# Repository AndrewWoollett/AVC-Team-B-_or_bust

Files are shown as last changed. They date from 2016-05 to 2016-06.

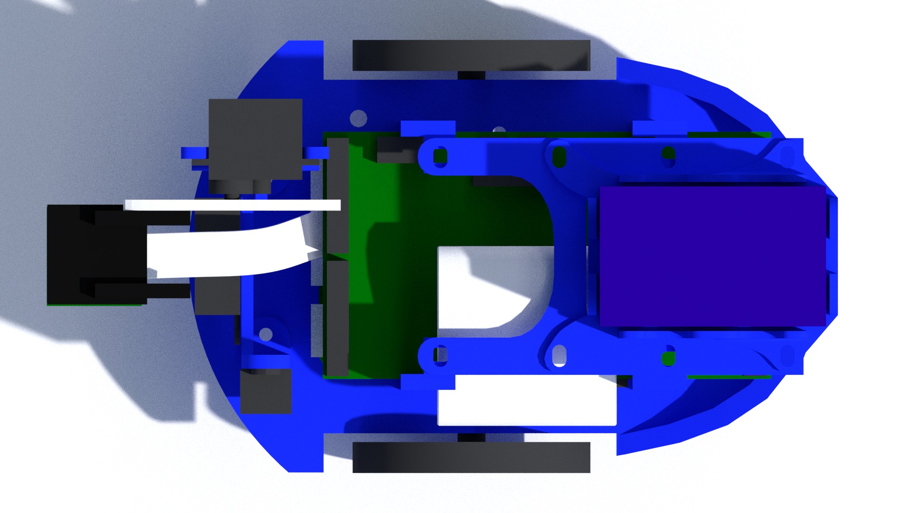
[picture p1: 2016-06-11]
Design/Images/Top.jpg

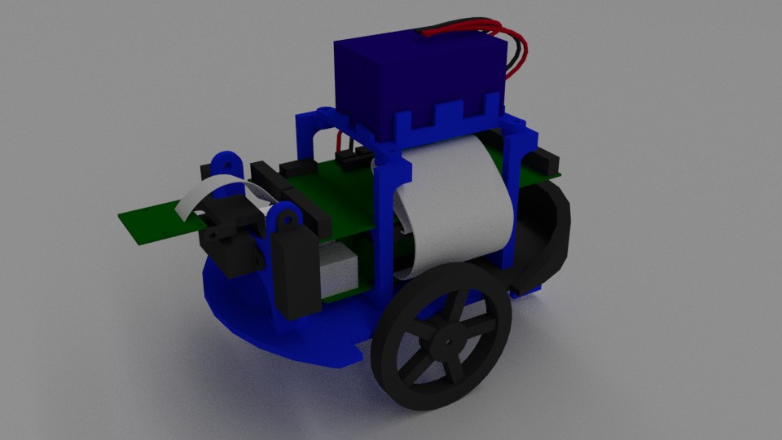
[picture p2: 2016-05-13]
Design/Images/0000.jpg

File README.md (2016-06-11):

# AVC-Team-B-_or_bust
Team repository for the AVC Project in ENGR101.
Team members include: David Scott, Daniel Sommerville, Ana Ramirez, Daniel Van Eijck and Andrew Woollett

Week 1 Plan (22nd April, just before the holidays/during the holidays)
Andrew: Set up the Github repository
David: Go over the AVC plan to make sure everything is completed
Daniel: SSH into the RPi
Daniel S: Put together the initial hardware components
Ana: Create weekly plan (table) and get key dates and people organised

Week 1 Review:
(Since it was the holidays, we only set up very simple goals as we knew we would not be able to complete much while away from uni).
Everyone completed their respective tasks for this week and we got the AVC plan in on time before the holidays.

Week 2 Plan (28th April, During and after the holidays):
(Minor work as part of this week is during the holidays and wouldnt be able to organise team meetings)
Andrew: Review and go over the skeleton code
David: Planning of the code to get the sensor working
Daniel V: Planning the code to get the robot working
Daniel S: Startng designing hardware construction
Ana: Arrange communication, sorting out meetings outside of lab time.

Week 2 Review:
Because of the holidays, again we couldn't get a lot done in terms of coding, but we did as a group go over the skeleton code and began planning how to go about building on the skeleton code to get the basic function of the robot working.
Daniel made a full detailed plan of the design and hardware of the robot that he created on Blender. He had also already 3D printed a few of the basic components of the hardware.
Daniel V, Andrew, and Ana had a few problems with SSH-ing into the Rpi and finding the IP address, but this was just through simple errors of our own, rather than technical issues with the RPi.

Week 3 Plan (5th May):
Andrew: Begin coding to get the sensors working so that the basic "detection" part of the robot is operational
David: Continue producing documentation and overseeing and providing help with software
Daniel V: With Andrew, begin coding to get the sensors working so that the basic "detection" part of the robot is operational and begin on the basic movement of the robot
Daniel S: Continue with the construction, design, and printing of the hardware to have it completed by the start of our next official lab time (12th May).
Ana: Arrange meetings and delegate tasks as well as assist with the documentation and software

Week 3 Review:
We had a few issues this week with our RPi. On Friday, our robot short circuited, we believe because Daniel was constructing the robot while it was still turned on, resulting in a lot of our planned meeting time being used by trying to fix it. In the end, we had a to ask Elf for help, who gave us a new SD card.
This meant that we lost a lot of the code that we'd been working on since we were working on the Pi itself and hadn't uploaded any of the code to GitHub. Because of this, we've had to work significantly harder this week in order to regain our lost time and files.
Aside from our issues, Daniel S successfully completed printing out all the hardware and construction of the robot so that it is practical and functional, yet follows the "aesthetic" requirements of the project.
Andrew and Daniel S have both been working on regaining and improving the code that we have lost, with assistance from David and Ana. At the end of this week we have committed and saved and committed several files to GitHub for the software, but haven't actually run or tested anything yet, which we plan to do in our next meeting (12th May).

Week 4 Plan (12th May):
As an overall goal as a group, by our next designated lab time, we aim to be testing our robot on the official board, and hopefully be running the robot up to the B- mark (end of the second quadrant).
Andrew: Develop the code to enable the robot to turn at dead ends
David: Continue with documentation and assist with developing the code to get the robot to turn around the curved corners
Daniel V: Develop the code to enable the robot to turn at dead ends
Daniel S: Design a new back wheel and figure out a way for the robot to fit turn inside the maze.
Ana: Continue with documentation and assist with developing the code to get the robot to turn around the curved corners, as well as go over the code to get the gate opening (written by Daniel V), test it, and get it functional.

Week 4 Review (so far):
David has not showed up for our Thursday lab or the extra meeting we scheduled on Friday (absence yet to be explained).
Daniel S put the finishing touches on the hardware of robot, so that this part is complete so we are now free to run code on the robot to test it officially. We ran into a few problems when trying to test our code, one of them being that our RPi didn't have the lt and makefile files. So we asked Arthur and he gave us another updated SD card (again) with the correct files on it this time. By the end of Thursday's lab we had the robot moving and operational. It could roughly dectect a line and attempts very roughly to rectify itself back onto the line when it goes astray, however, we are still very pleased with this progress.
After our extra meeting on Friday (attended by Daniel V, Daniel S, and Ana), we made even further progress. We haven't got the gate working yet as we have been concentrating on getting the robot to follow the path, which at the moment it successfully does up until the second curve in the path (it can get through the first curve as it is not as sharp as the second curve).
By the end of the week (on Thursday the 19th), the robot was able to complete up to the B- mark on the path, meaning that one of our main goals was achieved. We also managed to fix the problem of the robot tipping over when it reversed (because of weight distribution), by relocating the placement of the battery on the robot. We noted that the back wheel of our robot was slightly faulty and meant that the robot occasionally went off on the wrong direction, so we made the plan to replace this wheel with a marble so it is able to move more freely. Daniel wrote down a lot of his testing process this week in order to get the camera sensing the line properly in order to get it up to the B- mark, as well as figuring out how to deal with T junctions and dead-ends. This documentation can be found in the document “Daniel’s Documentation (week 4)”

Week 5 plan (19th May): Our overall group goal this week is to get the robot operational up to the entrance to the maze, and have a plan of how to code the maze. 
Daniel V and Daniel S: refine code further so that the robot is able to deal with right angled turns, T junctions, and dead ends, so that the robot can reach the entrance of the maze.
Ana: Continue with the documentation.
David, Andrew, and Ana: begin researching and working on a plan of how to get the robot to complete the maze.

Week 5 Review: this week we kept running into the regular problem of the lab being constantly full, so much so that we weren’t allowed in unless it was our regular lab time, or that only1 or 2 members of the team were allowed in at once. In this situation of only a few team members being allowed in at once, we decided to place getting the robot up to the entrance of the maze as a priority over beginning working on the maze code, which meant that we didn’t advance very quickly with our maze code this week. However, by the end of the week, we successfully got the robot reaching the entrance of the maze with around 80% consistency. PID just needs to be refined further in order to get this working. And we did end up with a general plan on how to tackle the maze code, and managed to get the sensors to detect the red square at the start of the maze, so that the sensors are activated.

Week 6 plan (26th May): We predict that since this is the final week of the AVC until it is tested, the lab will be packed almost all the time, so our only options are to get in early, or to work on code outside the lab. We are currently feeling very confident about our robot, so we have set the goal of the robot completing 100% of the maze by the time it comes to be tested.
Daniel V: refine PID so that the robot is able to follow the tape more consistently.
Rest of the team: create the Maze code and the PID for the sensors.

Week 6 Review: As we predicted, it is very difficult this week to get spots in the lab, so we ended up meeting outside the lab to create some basic maze code that we would test on the robot at our next opportunity. This rough code worked very well as a starter, so from here we began to create the PID for the robot. Daniel V refined the code further so that it could get up to the entrance of the maze much faster and at a more consistently. However, an issue keeps coming up where at the first right angled junction (before the B- mark), the robot goes into the dead end, and to escape it, it reverses, and then retraces its steps, back to the start of the maze. This occurs probably 40% of the time, and we’ve decided that there’s nothing much we can do about it, and it will be ok, especially since during the final testing, we are allowed to restart the robot as many times as we want within those 15 minutes. After implementing the maze PID, we had a few errors were occasionally the robot would get stuck on a corner, but improving PID fixed this issue fairly easily. By Tuesday the 31st (2 days before our final test), the robot was able to fully complete all 4 quadrants fairly consistently and at a decent speed. On Thursday, our robot was officially tested, and completed 100% of the maze, sending us to an A+, in 1 minute 5 seconds, a time and grade that we were all very happy with, and because of this, we made it into The AVC finals, to face off against the rest of the highest scoring robots.

AVC Finals: Our main plan for the AVC finals was just to increase the robot's speed without decreasing its ability to move through the board and maze, so we simply increased the speed slightly, and edited out the gate code (since there was no gate in the finals). When our robot came to be tested, it completed the course in 1 minute 1 second, which ended up being the fastest robot out of all the others, meaning that our group took out the award for the fastest AVC robot.

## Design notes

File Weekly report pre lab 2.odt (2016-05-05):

Pre 2nd lab progress.

Design

Model is designed complete and is just awaiting printing and tests. The only problems we have spotted with it so far is that if the robot may tip forward if stopped suddenly. Though this may be fine as our robot is back heavy and the wheels are slightly shifted towards the front.

We don’t have to worry about the robot falling back as we have a third ‘support wheel’ that holds up the rear and simply follows the influence of the two powered wheels.

The robot is of somewhere between an egg shape and an oval in overall shape because we decided that the best shape as a group would be a circle. But due to the size of the rpi we have made a compromise to flatten the circle at the sides, with the oval being slightly wider at the front.

Coding

At this stage we’ve assessed the skeleton code and have assigned roles on what to work on. Due to the holidays our group hasn’t been able to work on actually developing the code. But we do have a great idea on how we are going to get the robot to read the images it detects, and from that we should be rather quick to get our ideas into code.

Meetings

Unfortunately, our group hasn’t been able to get in many meetings due to when the lab is available. But one was held on the Wednesday before our lab by three members of the team. Due to the other two not being able to get to the lab at that time.

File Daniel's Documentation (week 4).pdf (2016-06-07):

### The following is Daniel’s documentation up to Friday the 20th May:

First version of code:

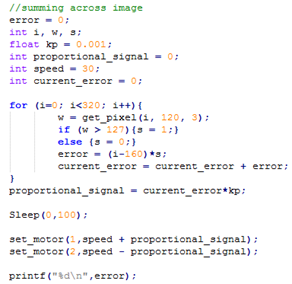
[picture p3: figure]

The code above is the first set of code that we tested. It has implemented the first stage of PID control (proportional). The proportional signal equals the current error (sum) multiplied by the constant Kp. The proportional signal Is then entered directly into the set_motor line of code. After working out the bugs and running the code above, the robot can drive in a straight line and also follow the line around gentle curves. This code only scans one line of pixels across the image. In order to get more information from the image, our next step was to split the line into 4 segments so the robot could make decisions based on the error value of each segment of the line.

Second version of Code:

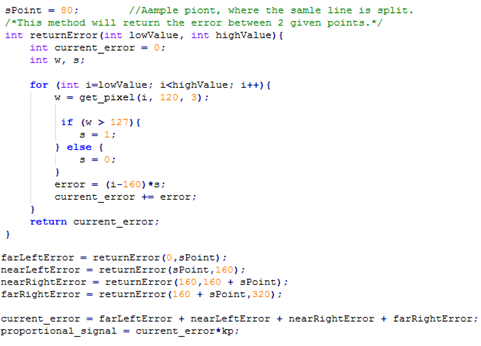
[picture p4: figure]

In the code above, the current error has been split into 4 separate error values: farLeftError, nearLeftError, nearRightError, farRightError. This splits the image into 4 quarters and calculates error values for each quarter. The returnError(int lowValue, int highValue) method returns the error value for each quarter. lowValue and highValue define the edges of each quarter of the image. The current_error has now been updated to be the sum of all four error values.

Third version of Code:
Instead of scanning one line of pixels across the image, we decided to scan 3 lines horizontally across the image. Each line was scanned in 4 segments and an error sum calculated and stored was stored in a 2D array.

We found a problem where all the pixels on the right side of the camera returned weird values. After checking the code we knew it was a hardware problem. This problem was caused by the camera being not plugged in properly. This was fixed by switching off the robot and pushing the camera in. This fixed the problem.

Fourth version of Code:
On Friday 20, I changed the code a lot. Dan had the idea to read vertically as well as horizontally, so I have created 7 new methods. A checkAcross method which scans across the image at a given height and returns true if there are more than 10 white pixels. There is also a checkDown which does the the same as checkAsross but checks a vertical line at a given position.
The other 5 methods are; top, mid, bot, left and right which calls one of the check methods. For example, top calls return checkAcross(60); which will scan across the image at height 60 and pass on the boolean value. This means that I can easily call call top() or !top() when checking what is in front of the robot. This picture shows what lines should be true or false for each different scenario.

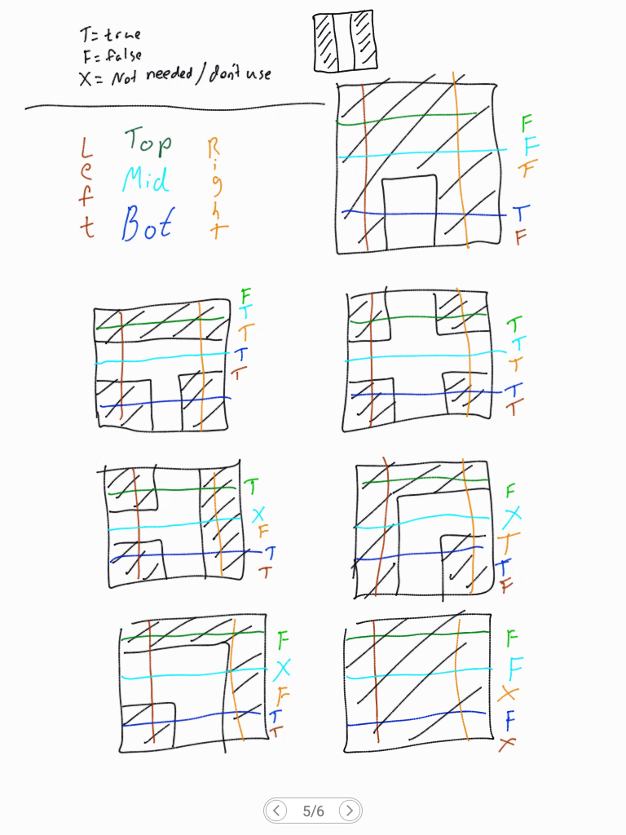
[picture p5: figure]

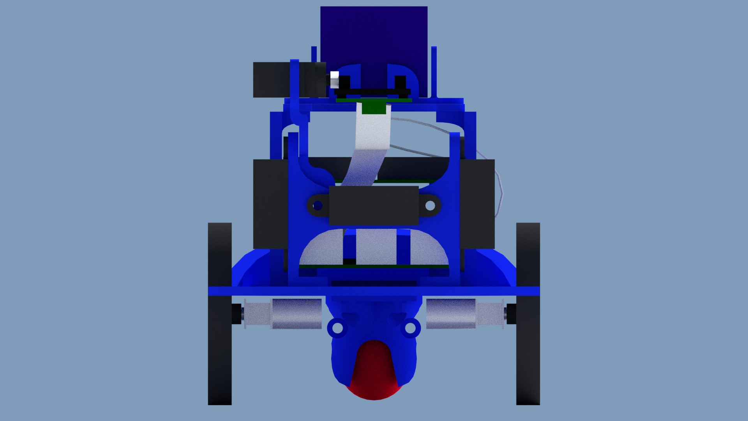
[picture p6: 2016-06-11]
Design/Images/Front.jpg

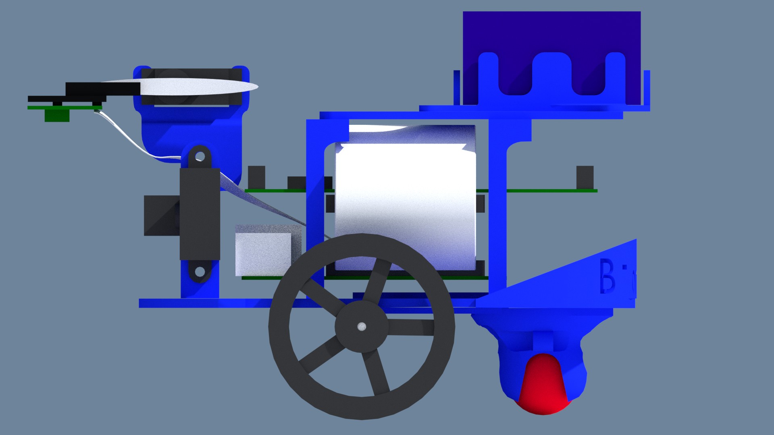
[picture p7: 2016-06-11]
Design/Images/Left.jpg

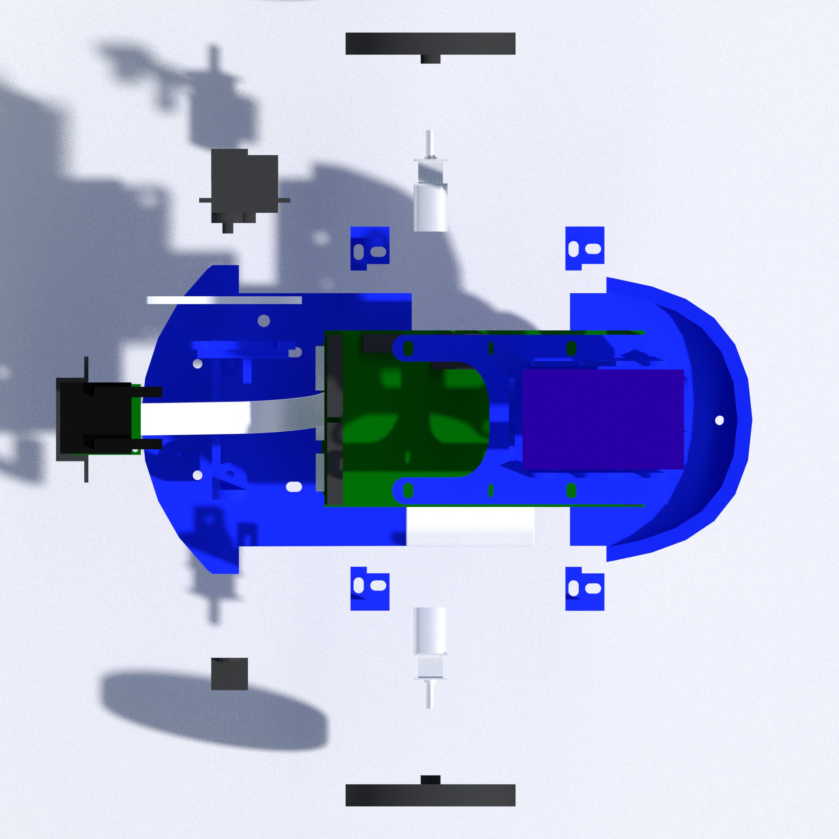
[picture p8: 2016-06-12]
Design/Images/Exploded Views/Exploded Top.jpg

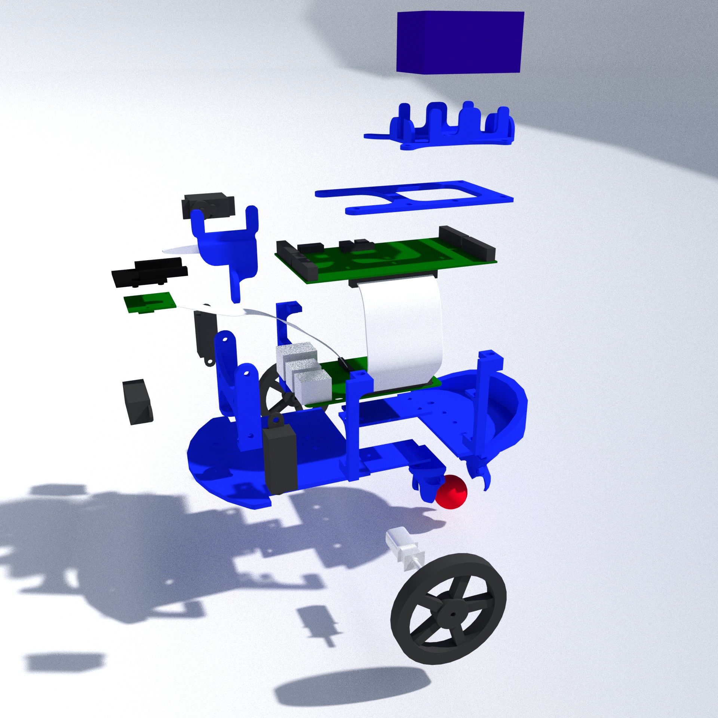
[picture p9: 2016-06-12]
Design/Images/Exploded Views/Exploded 0.jpg

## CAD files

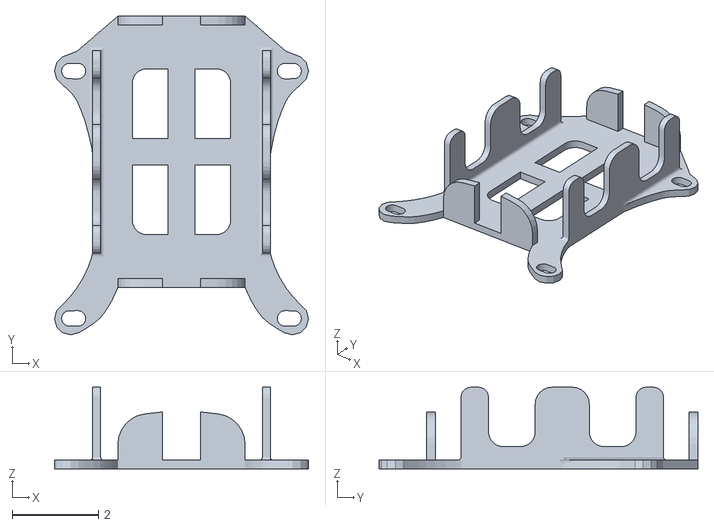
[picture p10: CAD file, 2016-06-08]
Design/BatteryHolder.stl
5.90 x 7.41 x 1.90

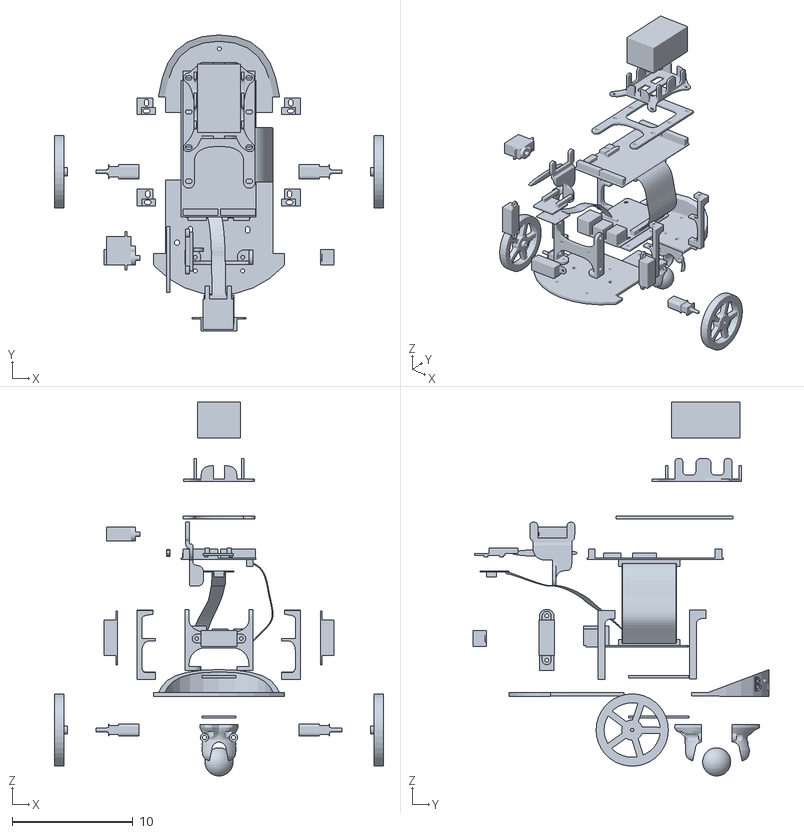
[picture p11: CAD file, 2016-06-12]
Design/Images/Exploded Views/Exploded model.stl
27.3 x 24.6 x 31.0

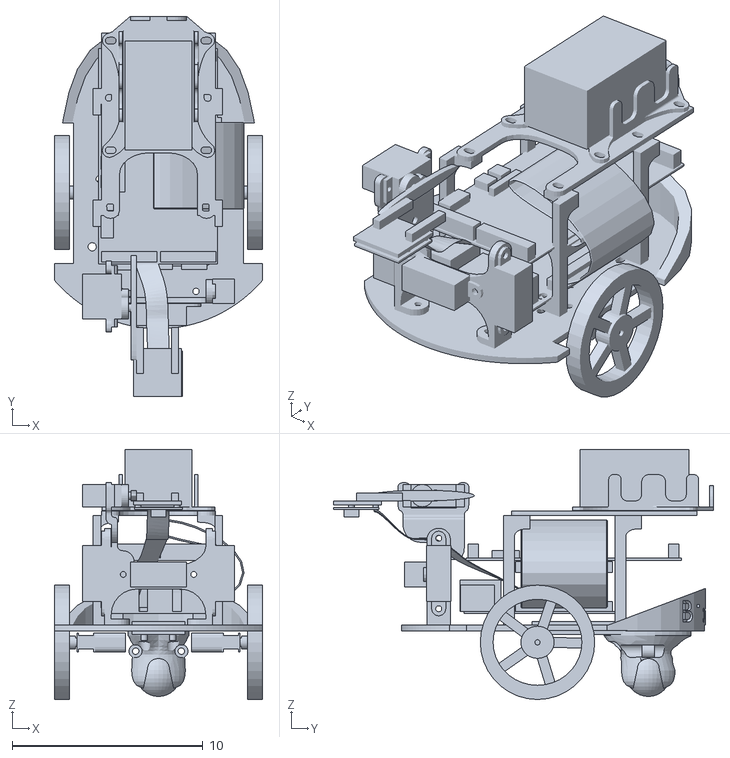
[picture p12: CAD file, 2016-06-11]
ScaleModel.stl
10.9 x 20.0 x 13.1

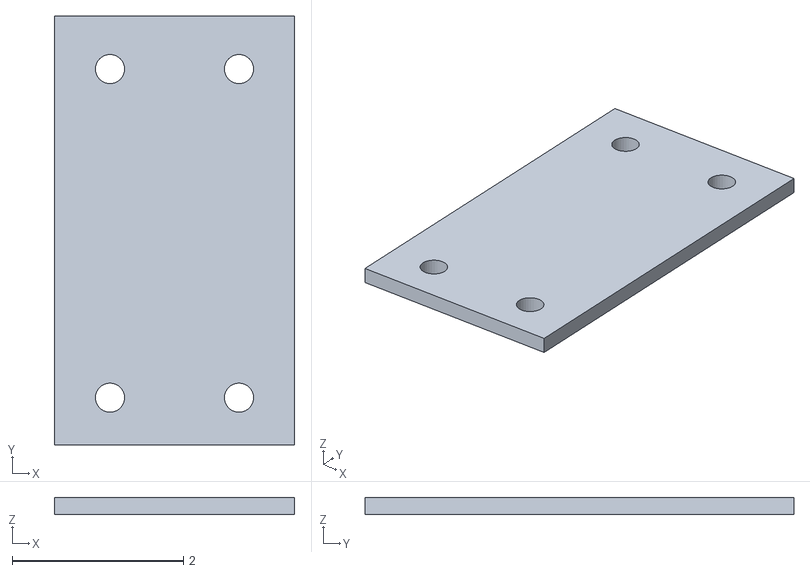
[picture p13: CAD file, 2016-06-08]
Design/Brace.stl
2.80 x 5.00 x 0.2

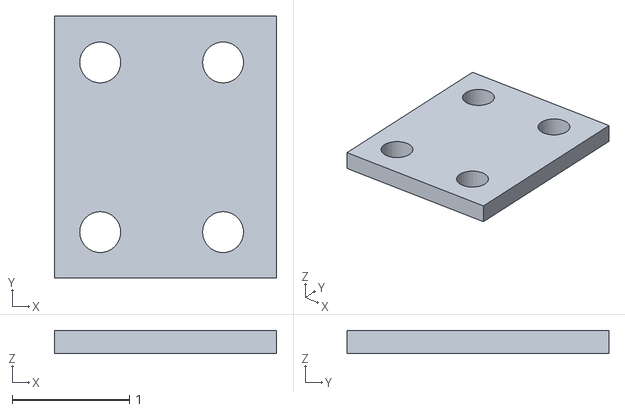
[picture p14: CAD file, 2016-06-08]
Design/WheelHoleTest.stl
1.90 x 2.24 x 0.2

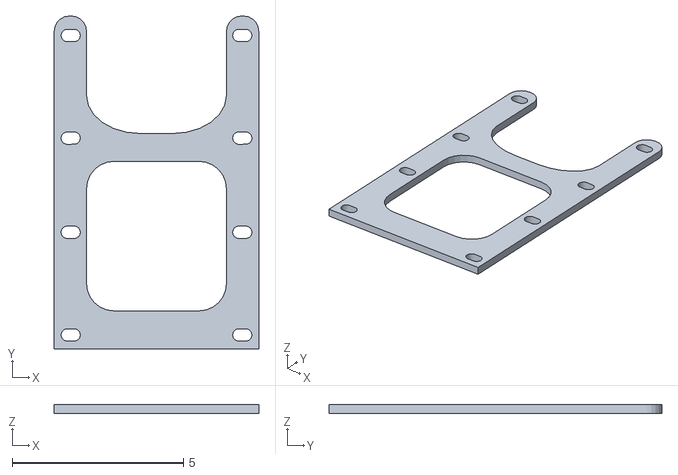
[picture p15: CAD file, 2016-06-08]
Design/BatterySupport.stl
5.98 x 9.73 x 0.25

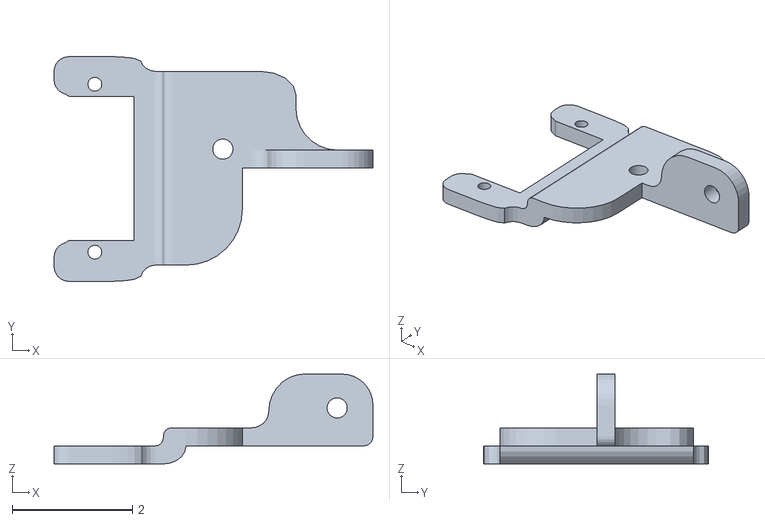
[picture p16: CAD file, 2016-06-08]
Design/Servo holder.stl
5.30 x 3.73 x 1.49

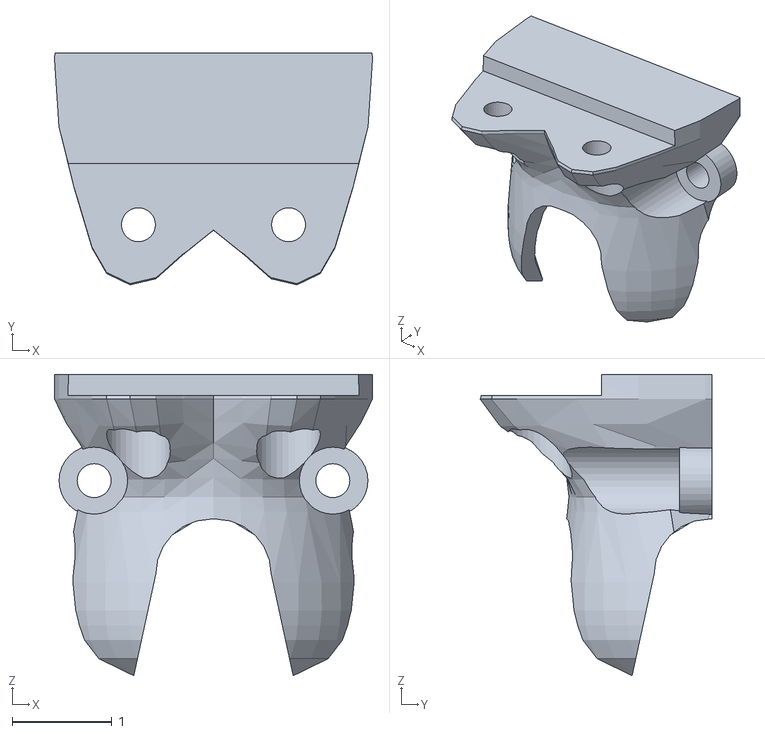
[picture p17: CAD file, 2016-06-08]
Design/Fixed Wheel.stl
3.19 x 2.32 x 3.02

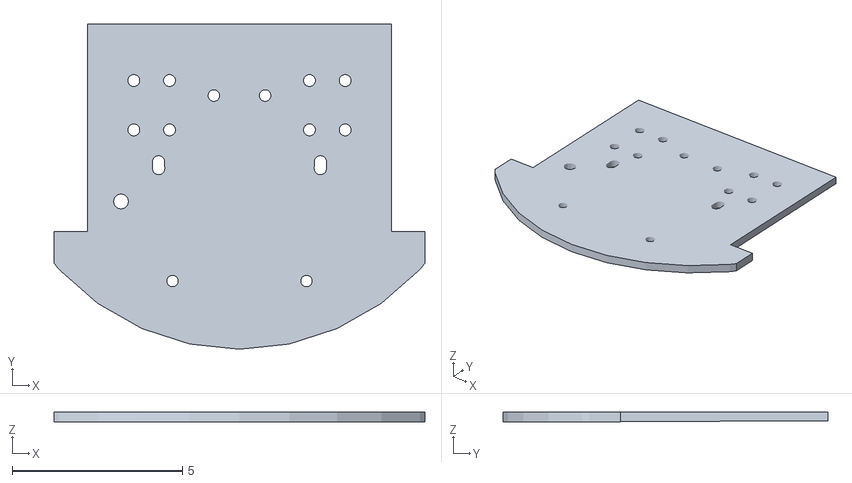
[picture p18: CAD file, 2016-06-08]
Design/BaseFront.stl
10.9 x 9.56 x 0.3

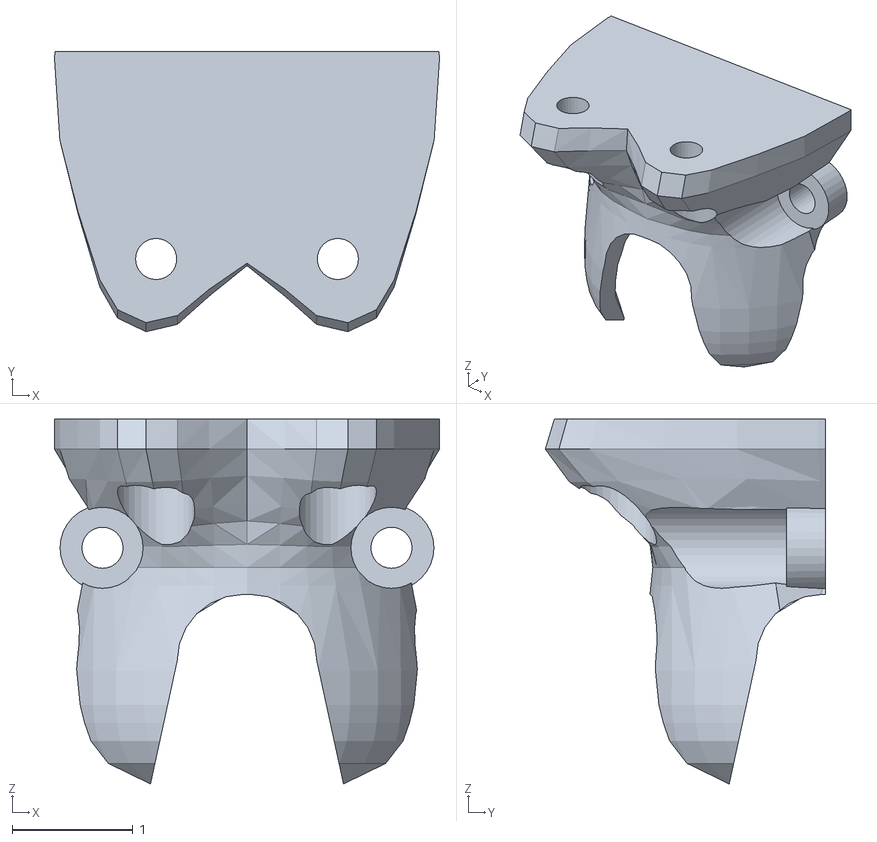
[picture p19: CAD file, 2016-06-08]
Design/Wheel2.stl
3.19 x 2.32 x 3.02

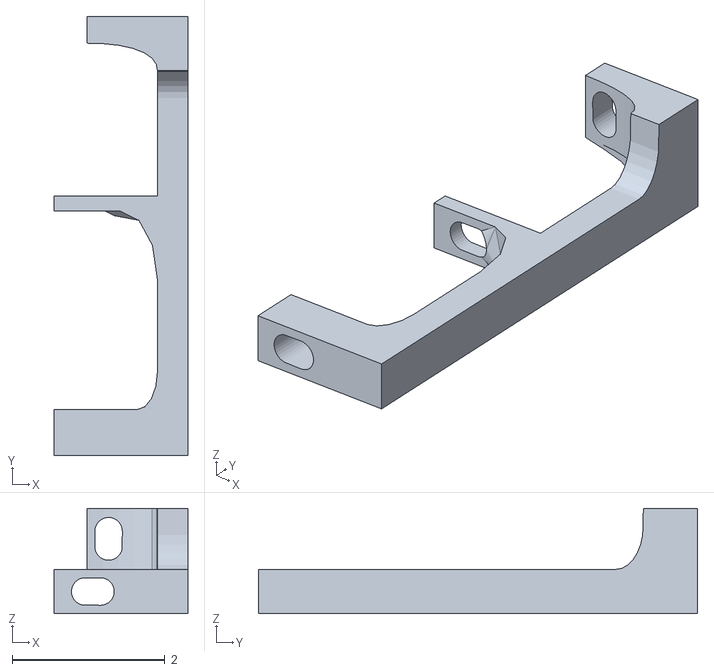
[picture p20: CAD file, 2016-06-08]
Design/Strut02.stl
1.75 x 5.75 x 1.38

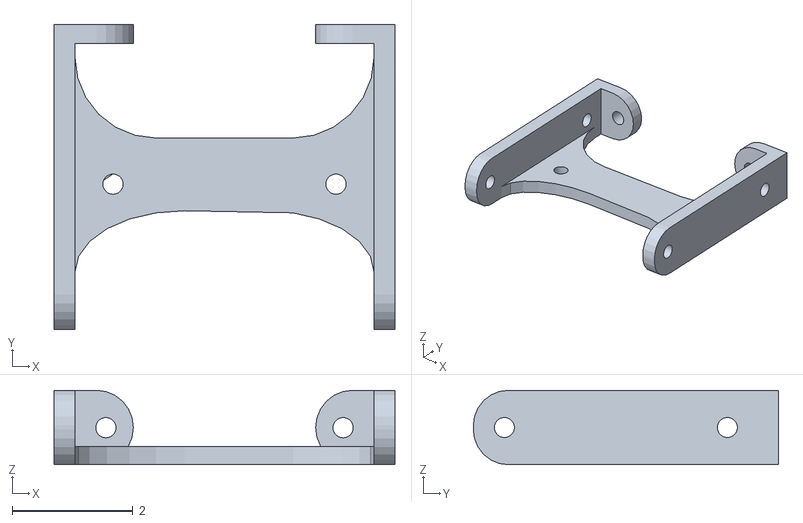
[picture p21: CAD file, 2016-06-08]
Design/Front.stl
5.66 x 5.07 x 1.24

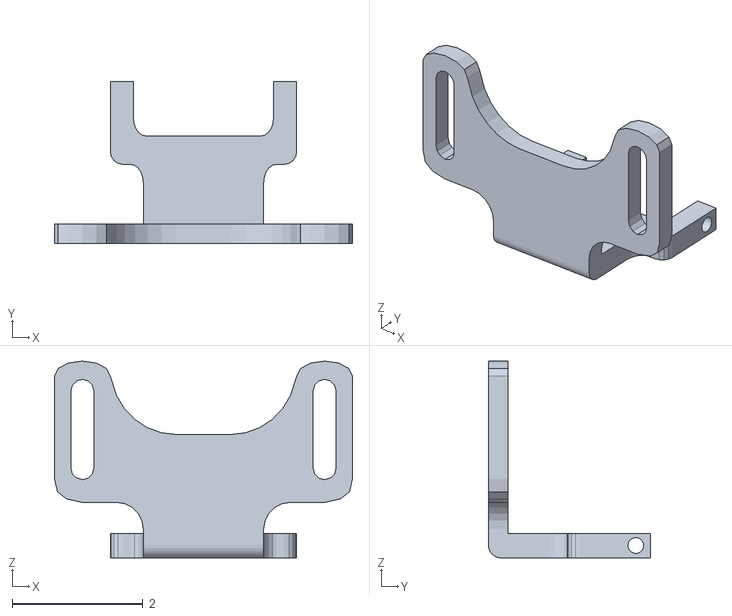
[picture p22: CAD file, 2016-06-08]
Design/CameraHolder.stl
4.55 x 2.48 x 3.01

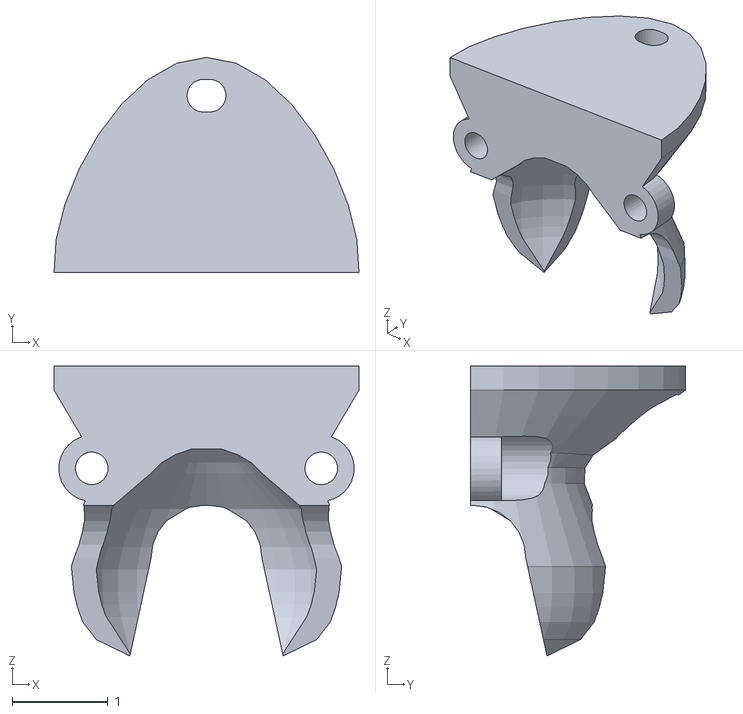
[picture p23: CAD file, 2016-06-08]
Design/Wheel1.stl
3.18 x 2.25 x 3.02

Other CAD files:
Design/BaseBack.stl

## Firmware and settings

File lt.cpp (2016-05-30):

#include <stdio.h>
#include <time.h>
#include <string.h>

// sudo gcc -Wall
extern "C" int init_hardware();
extern "C" int init(int d_lev);

extern "C" int take_picture();
extern "C" char get_pixel(int row, int col, int color);
extern "C" void set_pixel(int col, int row, char red,char green,char blue);

extern "C" int open_screen_stream();
extern "C" int close_screen_stream();
extern "C" int update_screen();
//extern "C" void GetLine(int row,int threshold);
extern "C" int display_picture(int delay_sec,int delay_usec);
extern "C" int save_picture(char filename[5]);

extern "C" int set_motor(int motor,int speed);

extern "C" int read_analog(int ch_adc);
extern "C" int Sleep(int sec, int usec);
extern "C" int select_IO(int chan, int direct);
extern "C" int write_digital(int chan,char level);
extern "C" int read_digital(int chan);
extern "C" int set_PWM(int chan, int value);

extern "C" int connect_to_server( char server_addr[15],int port);
extern "C" int send_to_server(char message[24]);
extern "C" int receive_from_server(char message[24]);

bool gate = false;
float kp = 0.003;        //tune this
float kd = 0.0012;        //tune this

int turnSpeed = 50;
int speed = 50;
int intError = 0;
int proportional_signal = 0;


int sPoint = 80;        //Sample piont, where the sample line is split.
bool redStop = false;
/*
*This method will return the error between 2 given points.
*/
int returnError(int height){
    float current_error = 0;
    int w, s;

    for (int i=0; i<320; i++){
        w = get_pixel(i, height, 3);
         if (w > 127){
            s = 1;
        } else {
            s = 0;
        }
        intError = (i-160)*s;
        current_error += intError;
    }
 return current_error;
}

bool checkAcross(int height){
        bool white = false;
    int w, s=0;
    for (int i=0; i<320; i++){
        w = get_pixel(i, height, 3);
        if (w > 135){
                s++;
         }
         if(s>20){
                white =  true;
        }
   }
return white;
}

bool checkDown(int pos){
        bool white = false;
    int w, s=0;
    for (int i=0; i<190; i++){
        w = get_pixel(pos, i, 3);
        if (w > 135){
        s++;
    }
    if(s>20){
        white =  true;
  }
}
return white;
}

bool top(){
  return checkAcross(20);
}
bool mid(){
  return checkAcross(120);
}
bool bot(){
  return checkAcross(200);
}
bool left(){
  return checkDown(10);
}
bool right (){
  return checkDown(310);
}

bool checkRed(){
        for (int i= 80; i<210; i++){
                int r = get_pixel(i, 120, 0);
                int g = get_pixel(i,120,1);
                int b = get_pixel(i,120,2);
                if (r >200 && g < 100 && b < 100){ //theory for red detection
                        printf("Red");
                        return true;
                }
        }
        return false;
}

void turnLeft(){

        while(!top()){
        take_picture();
        set_motor(1,-turnSpeed);
        set_motor(2,turnSpeed);

        Sleep(0,25);
        }

        set_motor(1,speed);
        set_motor(2,speed);

}

void turnRight(){

        while(!top()){
        take_picture();
        set_motor(1,turnSpeed);
        set_motor(2,-turnSpeed);
        Sleep(0,25);
        }

        set_motor(1,speed);
        set_motor(2,speed);
}
float kpMaze = 0.06;

void turnLeftMaze(){
        float right  = read_analog(0);
        set_motor(1,-50);
        set_motor(2,60);
}

void turnRightMaze(){
        float left  = read_analog(2);
        set_motor(1,80);
        set_motor(2,35);
}

void goFowardMaze(){
        float front = read_analog(1);

        float distance = read_analog(2);
        float signal = distance - 550;
        float propSignal = signal * kpMaze;
        set_motor(1, -propSignal + speed);
        set_motor(2, propSignal + speed);
//      printf("%f\n",distance);
}

int main(){

    init(0);
    // connect camera to the screen
    open_screen_stream();
    // set all didgital outputs to +5V
    for (int i =0; i < 8; i++){
    // set all digital channels as outputs
    select_IO(i,0);
    write_digital(i,1);
    }

    set_PWM(1,180);
    Sleep(2,0);
/*
    //open the gate
    connect_to_server("130.195.6.196", 1024);
    char password[24];
    send_to_server("Please");
    receive_from_server(password);
    send_to_server(password);
    Sleep(1, 0);
    gate = true;
    printf("Gate Open");
    set_motor(1, speed);
    set_motor(2, speed);
    Sleep(3, 0);
*/
while(0){
        // take camera shot
        take_picture();
        //summing across image
        intError = 0;
        float current_error = 0;
        float previous_error = 0;
        int derivative_signal;

        current_error = returnError(120);

        proportional_signal = current_error*kp;

        derivative_signal = (current_error - previous_error / 0.1) * kd;
        previous_error = current_error;

        set_motor(1,speed + proportional_signal - derivative_signal);
        set_motor(2,speed - proportional_signal + derivative_signal);

        if (!top() && !mid() && !bot() && !left() && !right()){
                set_motor(1,-50);
                set_motor(2,-50);
                Sleep(0,500000);
                printf("Stop\n");
        }

         if(top() && mid() && bot() && left() && right()){
                redStop  = true;
                break;
        }

        //Sleep is last so the motors dont update too late.
        Sleep(0,25);

        }
        speed = 45;
while(1){
        // take camera shot
        take_picture();
        //summing across image
        intError = 0;
        float current_error = 0;
        float previous_error = 0;
        int derivative_signal;

        current_error = returnError(120);

        proportional_signal = current_error*kp;

        derivative_signal = (current_error - previous_error / 0.1) * kd;
        previous_error = current_error;



        if (checkRed() && redStop){ //theory for red detection
                break;
        }

        // turn left at a T junction
        if(!top() && mid() && bot() && left() && right()){
                turnLeft();
                printf("t-junction\n");
                redStop  = true;
        }
        // turn 180 at dead end
        else if(!top() && !mid() && bot() && !left() && !right()){
                turnRight();
                printf("turn-180\n");
        }
        // stop and reverse when it cant see the line
        else if (!top() && !mid() && !bot() && !left() && !right()){
                set_motor(1,-50);
                set_motor(2,-50);
                Sleep(0,500000);
                printf("Stop\n");
        // turn left at sharp corners.
        }else if(!top() && mid() && bot() && left() && !right()){
                turnLeft();
                printf("Left\n");
        // turn right  at sharp corners.
        }else if(!top() && mid() && bot() && !left() && right()){
                turnRight();
                printf("Right\n");
        }//else{
        set_motor(1,speed + proportional_signal - derivative_signal);
        set_motor(2,speed - proportional_signal + derivative_signal);
       // }

        //Sleep is last so the motors c=dont update too late.
        Sleep(0,25);
}


        set_PWM(1,100);


        set_motor(1,0);
        set_motor(2,0);

while(0){
        int dis = read_analog(2);
        printf("%d\n",dis);
        Sleep(0,25);
        }
speed = 45;
while(1){

        int disRight = read_analog(2);
        int disFront = read_analog(1);
        int disLeft = read_analog(0);

        int minDis = 300;
        int maxDis = 0;

        if(disRight < 200){
                printf("right \n");
                turnRightMaze();
        }else if(disFront < minDis){
                goFowardMaze();
                printf("forward \n");
        }else if(disLeft < 200){
                printf("left \n");
                turnLeftMaze();
        }else{
        //      turnRightMaze();
        }

}
        goFowardMaze();

    // terminate hardware
    close_screen_stream();
    set_motor(1,0);
    set_motor(2,0);

    return 0;
}

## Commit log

2016-05-06 PID
    Using Java to test the PID concept.
    You must restart the program to change the type of correction factor.
2016-05-07 Updated PID test
    This is a better simulation of how the PID system should work.
    This method can easily navigate straight lines and curves.
    Right angles are not yet solved.
2016-05-13 Update lt.cpp
    The camera now reads 2 different parts, the left and right. The get summed together so this does not change the previous code effect.
2016-05-16 Added arrays to store the error signals for different positions.
    [lt.cpp]
2016-05-16 fixed bugs
    This should work now.
    [lt.cpp]
2016-05-18 Update lt.cpp
    added total error values for each line being scanned
    [lt.cpp]
2016-05-19 Add files via upload
    Scaffolding for ending the camera loop and beginning the sensor readings for the maze using red detection.
2016-05-19 Update lt.cpp
    better t-junction, dead end and reversing code
    [lt.cpp]
2016-05-20 Finished the new error checking methods
    I will overwright the lt.cpp file
    [temp.cpp]
2016-05-22 test for controlling servo
    real file is saved as temp
2016-05-23 Added the servo code.
2016-05-26 Update sensorTest.cpp
    Updated sensor for the maze. Beginning of code to detect the walls of the maze and to follow the right wall
2016-05-26 changed sensor channels
2016-05-26 test for moving forward with PID
2016-06-08 Added all the 3D printed parts
    [BaseBack.stl, BaseFront.stl, BatteryHolder.stl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]
2016-06-11 Added the final model
    [ScaleModel.stl]
2016-06-12 Added exploded views
    These images show how the robot was assembled.
2016-06-12 3D exploded model
    [Exploded model.stl]
